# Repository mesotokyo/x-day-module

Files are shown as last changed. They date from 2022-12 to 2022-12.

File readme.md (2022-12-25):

# X-DAY (a.k.a. musicboxmod)

X-DAY (development name: musicboxmod) is a music box synthesizer module using HK326 IC. Based on the reference circuit, but modified to allow playback speed (and pitch) control. In addition, this module can output a gate signal linked to the melody.

## Controls, inputs and outputs

 - `START` button: Playback ON/OFF control. The behavior depoends on jumper pin settings
 - `SPEED` knob: Control playback speed. Also pitch changes with playback speed
 - `MOD CV IN`: Modulation input to change the playback speed
 - `TRIG IN`: Trigger input to control Playback ON/OFF (the same as `START` button)
 - `AUDIO OUT`: Audio signal output
 - `GATE OUT`: Gate signal output
 - `CV OFFSET`(trimmer resistor on PCB): You can change CV input offset. Recommended position is almost "2 o'clock" 
 - `MODE` (jumper pin on PCB): You can change the  behavior of the `START` button and the `TRIG IN` input. See table 1.
 - `SL` (jumper pin on PCB): You can change the  behavior of the `START` button and the `TRIG IN` input. See table 1.

### Table 1: `MODE` and `SL` jumper pin settings

| MODE pin setting | SL pin setting | Behavior |
| --- | --- | --- |
| Vdd | Vdd | ON/OFF |
| Vdd | Vss | ONE SHOT, NON RE-TRIGGER |
| Vss | Vdd | ONE SHOT, RE-TRIGGER |
| Vss | Vss | PLAY ALL SONGS |

 - note 1: `Vss` is opposite position of `Vdd`.
 - note 2: `ONE SHOT` means "play one song and then stop".
 - note 3: `RE-TRIGGER` means "stop current song and play next song when the button is pushed".

## Schematic

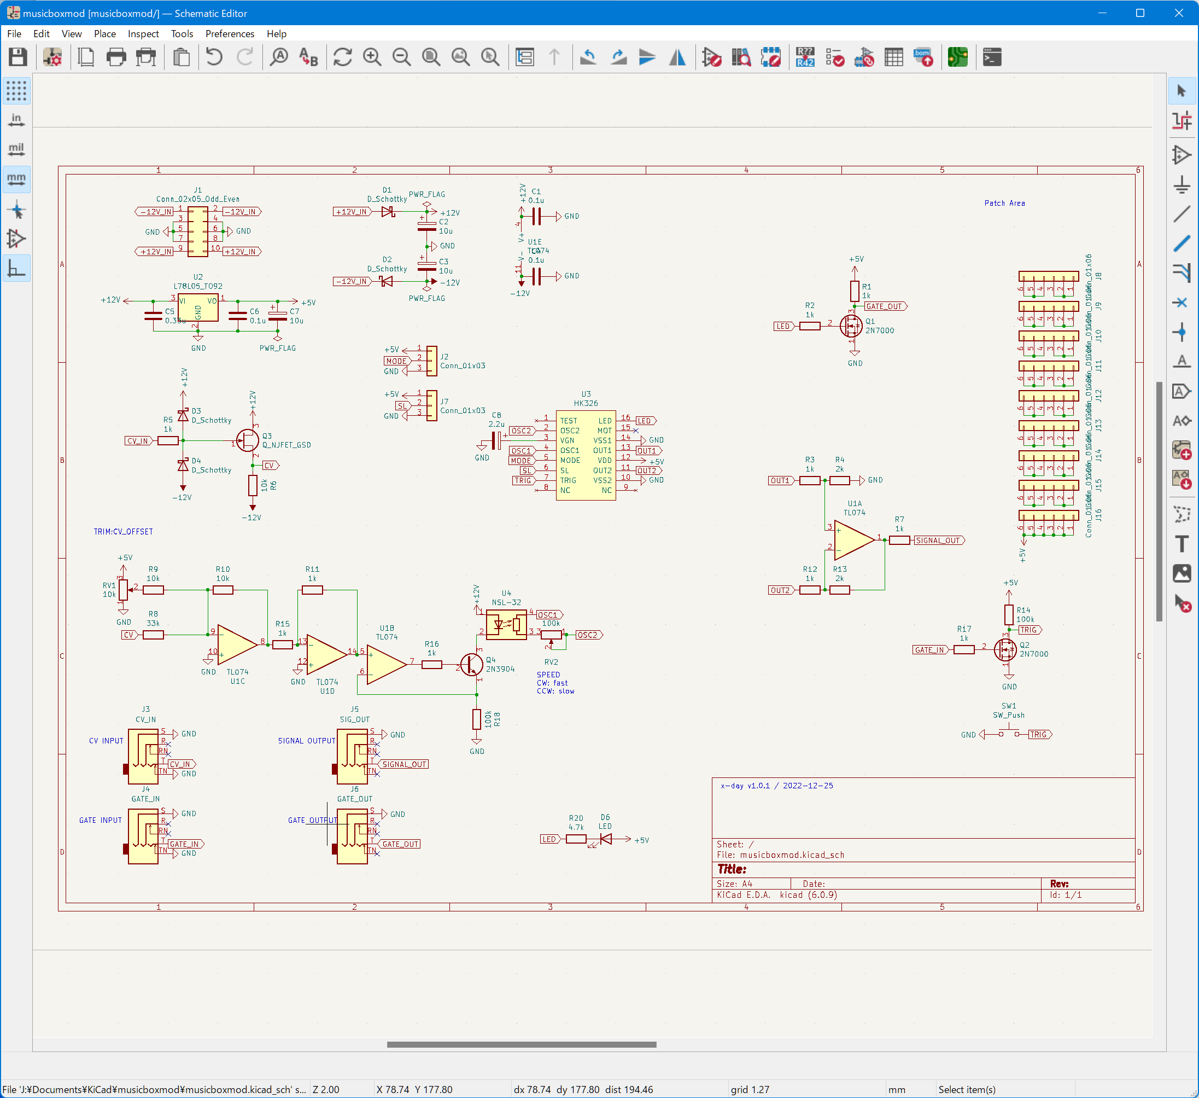
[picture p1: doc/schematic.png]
Schematic


## PCB image

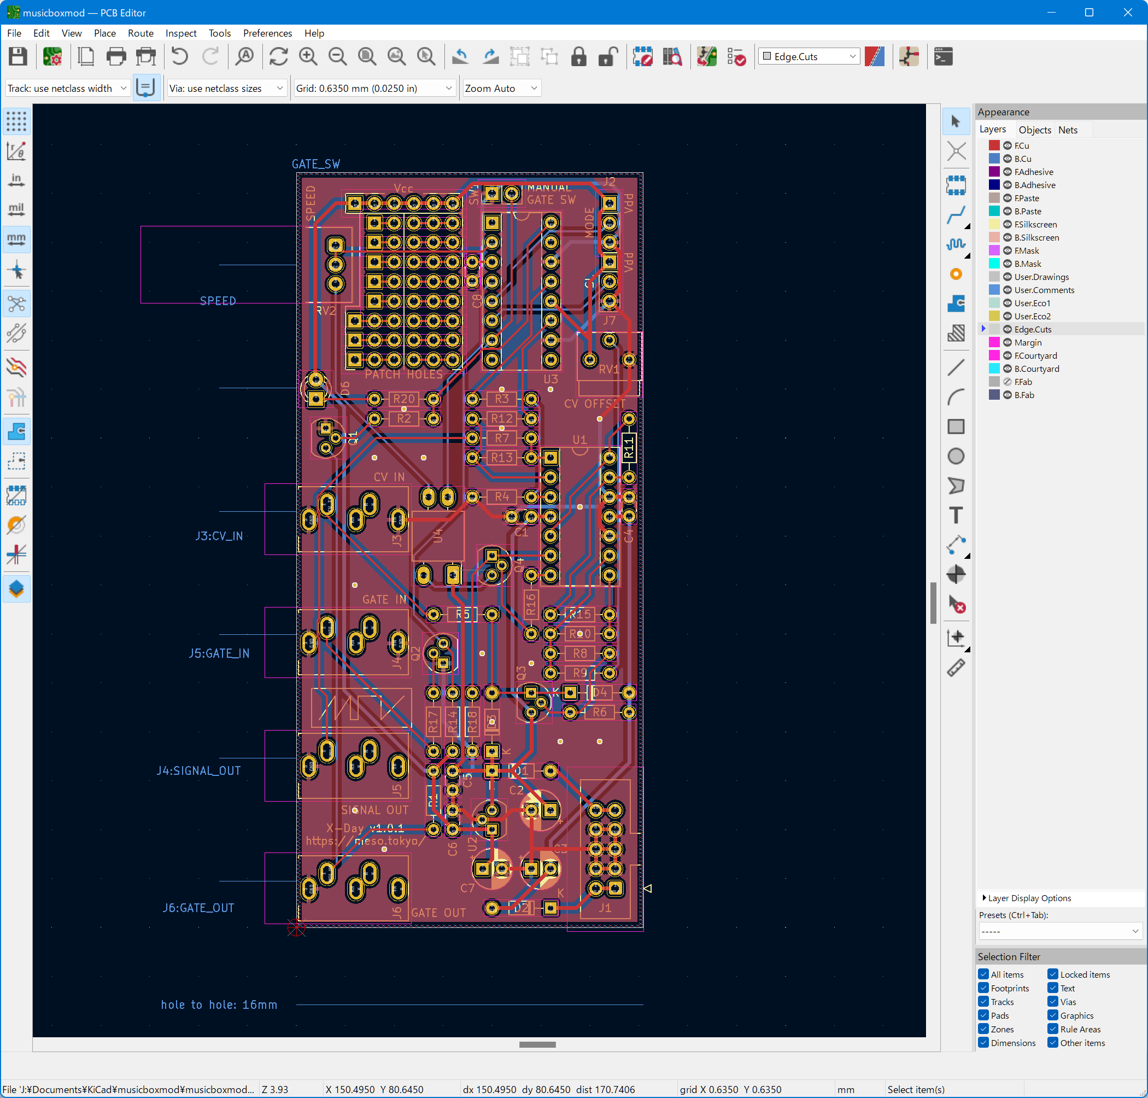
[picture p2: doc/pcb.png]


## KiCAD files

This KiCAD project uses my KiCAD footprint and symbol library (https://github.com/mesotokyo/mst-kicad-lib). If you want to modify the schematic and PCB, please import this library.

## gerber

Please check [gerber](gerber) directory.

# Licenses

Creative Commons CC-BY 4.0 (https://creativecommons.org/licenses/by/4.0/)

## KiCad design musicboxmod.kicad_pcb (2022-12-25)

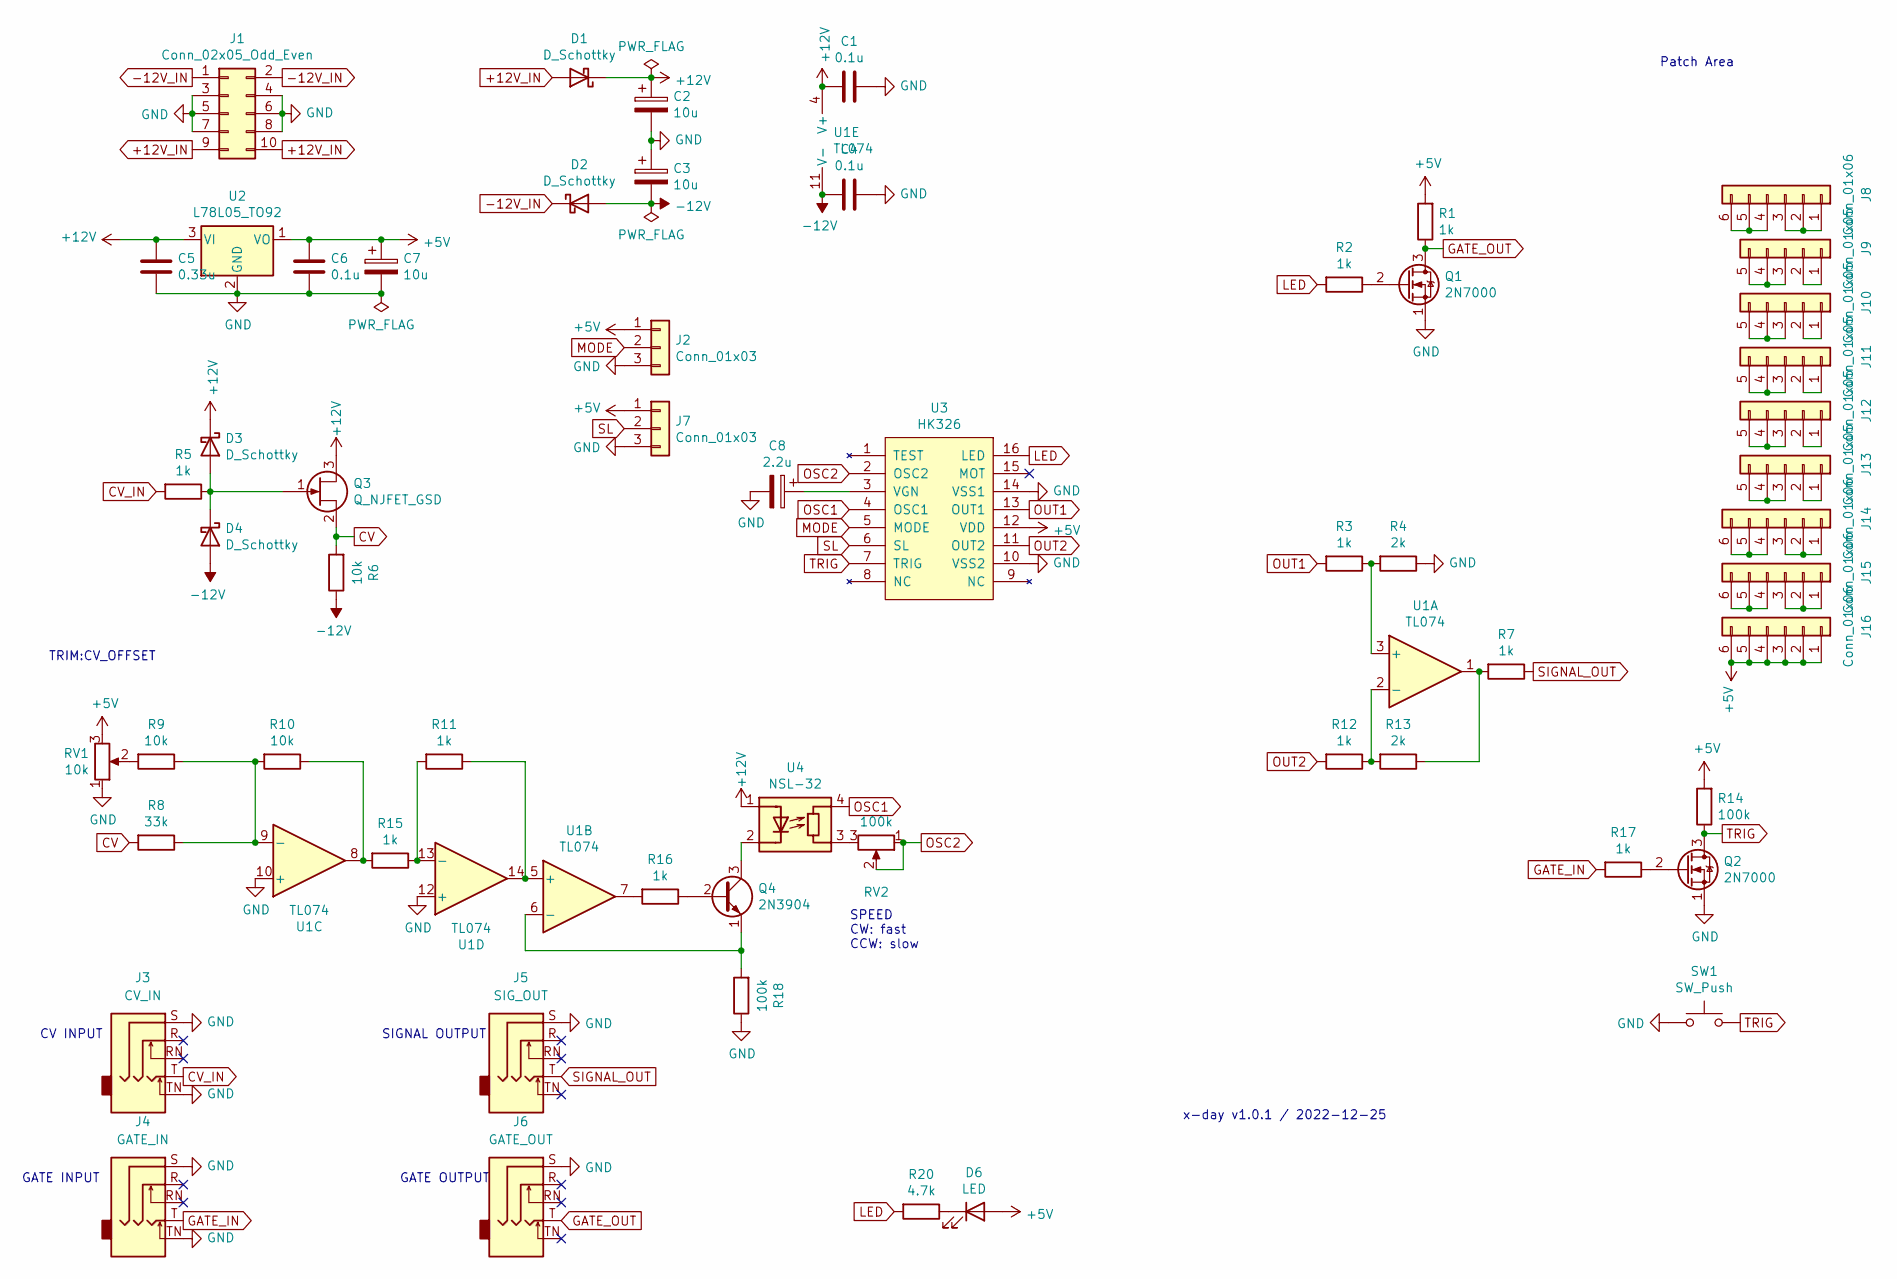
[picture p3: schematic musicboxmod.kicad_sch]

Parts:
C1, C4, C6: 0.1u; C_Disc_D3.0mm_W1.6mm_P2.50mm
C2, C3, C7: 10u; CP_Radial_D5.0mm_P2.50mm
C5: 0.33u; C_Disc_D3.0mm_W1.6mm_P2.50mm
C8: 2.2u; C_Disc_D3.0mm_W1.6mm_P2.50mm
D1, D2, D3, D4: D_Schottky; D_DO-34_SOD68_P7.62mm_Horizontal
D6: LED; LED_D3.0mm
J1: Conn_02x05_Odd_Even; IDC-Header_2x05_P2.54mm_Vertical
J2, J7: Conn_01x03; PinSocket_1x03_P2.54mm_Vertical
J3: CV_IN; Jack_3.5mm_CUI_SJ1-3535NG_Horizontal
J4: GATE_IN; Jack_3.5mm_CUI_SJ1-3535NG_Horizontal
J5: SIG_OUT; Jack_3.5mm_CUI_SJ1-3535NG_Horizontal
J6: GATE_OUT; Jack_3.5mm_CUI_SJ1-3535NG_Horizontal
J8, J14, J15, J16: Conn_01x06; PinHeader_1x06_P2.54mm_Vertical
J9, J10, J11, J12, J13: Conn_01x05; PinHeader_1x05_P2.54mm_Vertical
Q1, Q2: 2N7000; TO-92
Q3: Q_NJFET_GSD; TO-92
Q4: 2N3904; TO-92
R1, R2, R3, R5, R7, R11, R12, R15, R16, R17: 1k; R_Axial_DIN0204_L3.6mm_D1.6mm_P7.62mm_Horizontal
R4, R13: 2k; R_Axial_DIN0204_L3.6mm_D1.6mm_P7.62mm_Horizontal
R6, R9, R10: 10k; R_Axial_DIN0204_L3.6mm_D1.6mm_P7.62mm_Horizontal
R8: 33k; R_Axial_DIN0204_L3.6mm_D1.6mm_P7.62mm_Horizontal
R14, R18: 100k; R_Axial_DIN0204_L3.6mm_D1.6mm_P7.62mm_Horizontal
R20: 4.7k; R_Axial_DIN0204_L3.6mm_D1.6mm_P7.62mm_Horizontal
RV1: 10k; Potentiometer_Bourns_3339S_Horizontal
RV2: 100k; Potentiometer_Alps_RK097_Single_Horizontal
SW1: SW_Push; PinHeader_1x02_P2.54mm_Vertical
U1: TL074; DIP-14_W7.62mm_Socket
U2: L78L05_TO92; TO-92
U3: HK326; DIP-16_W7.62mm_Socket
U4: NSL-32; Luna_NSL-32

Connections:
+5V: C6.2, C7.1, D6.2 (A), J2.1, J7.1, J16.1, J16.2, J16.3, J16.4, J16.5, J16.6, R1.2, R14.2, RV1.3, U2.1 (VO), U3.12 (VDD)
+12V: C1.1, C2.1, C5.2, D1.1 (K), D3.1 (K), Q3.3 (D), U1.4 (V+), U2.3 (VI), U4.1 (A)
+12V_IN: D1.2 (A), J1.9, J1.10
-12V: C3.2, C4.1, D2.2 (A), D4.2 (A), R6.1, U1.11 (V-)
-12V_IN: D2.1 (K), J1.1, J1.2
CV: Q3.2 (S), R6.2, R8.2
CV_IN: J3.T, R5.2
GATE_IN: J4.T, R17.2
GATE_OUT: J6.T, Q1.3 (D), R1.1
GND: C1.2, C2.2, C3.1, C4.2, C5.1, C6.1, C7.2, C8.2, J1.3, J1.4, J1.5, J1.6, J1.7, J1.8, J2.3, J3.S, J3.TN, J4.S, J4.TN, J5.S, J6.S, J7.3, Q1.1 (S), Q2.1 (S), R4.1, R18.1, RV1.1, SW1.1, U1.10 (+), U1.12 (+), U2.2 (GND), U3.10 (VSS2), U3.14 (VSS1)
LED: R2.2, R20.2, U3.16 (LED)
MODE: J2.2, U3.5 (MODE)
unnamed: C8.1, U3.3 (VGN)
unnamed: D3.2 (A), D4.1 (K), Q3.1 (G), R5.1
unnamed: D6.1 (K), R20.1
unnamed: J8.1, J8.2, J8.3
unnamed: J8.4, J8.5, J8.6
unnamed: J9.1, J9.2
unnamed: J9.3, J9.4, J9.5
unnamed: J10.1, J10.2
unnamed: J10.3, J10.4, J10.5
unnamed: J11.1, J11.2
unnamed: J11.3, J11.4, J11.5
unnamed: J12.1, J12.2
unnamed: J12.3, J12.4, J12.5
unnamed: J13.1, J13.2
unnamed: J13.3, J13.4, J13.5
unnamed: J14.1, J14.2, J14.3
unnamed: J14.4, J14.5, J14.6
unnamed: J15.1, J15.2, J15.3
unnamed: J15.4, J15.5, J15.6
unnamed: Q1.2 (G), R2.1
unnamed: Q2.2 (G), R17.1
unnamed: Q4.1 (E), R18.2, U1.6 (-)
unnamed: Q4.2 (B), R16.1
unnamed: Q4.3 (C), U4.2 (K)
unnamed: R3.1, R4.2, U1.3 (+)
unnamed: R9.2, RV1.2
unnamed: R10.1, R15.2, U1.8
unnamed: R8.1, R9.1, R10.2, U1.9 (-)
unnamed: R11.1, U1.5 (+), U1.14
unnamed: R11.2, R15.1, U1.13 (-)
unnamed: R12.1, R13.2, U1.2 (-)
unnamed: R7.2, R13.1, U1.1
unnamed: R16.2, U1.7
unnamed: RV2.3, U4.3 (R)
OSC1: U3.4 (OSC1), U4.4 (R)
OSC2: RV2.1, RV2.2, U3.2 (OSC2)
OUT1: R3.2, U3.13 (OUT1)
OUT2: R12.2, U3.11 (OUT2)
SIGNAL_OUT: J5.T, R7.1
SL: J7.2, U3.6 (SL)
TRIG: Q2.3 (D), R14.1, SW1.2, U3.7 (TRIG)

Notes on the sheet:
CV INPUT
SIGNAL OUTPUT
TRIM:CV_OFFSET
GATE INPUT
x-day v1.0.1 / 2022-12-25
Patch Area
GATE OUTPUT
SPEED CW: fast CCW: slow

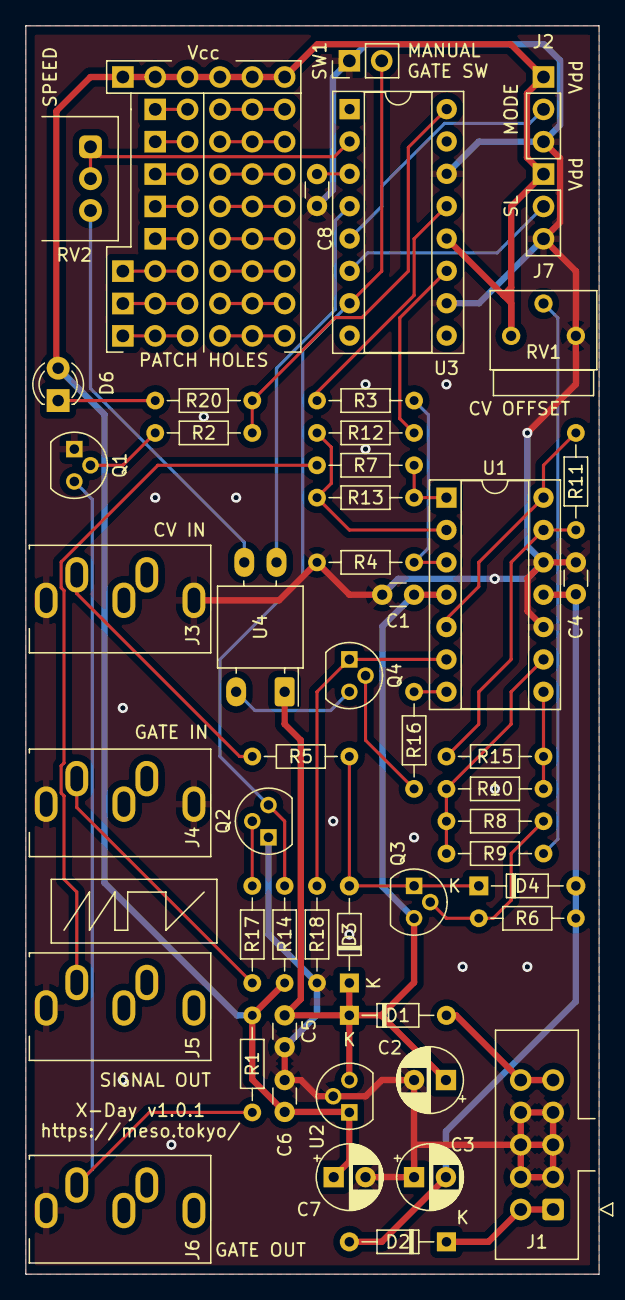
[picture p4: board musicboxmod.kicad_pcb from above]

Board: 2 copper layers, 45.0 x 98.0 mm, 59 parts (0 on the bottom side), 53 nets.
